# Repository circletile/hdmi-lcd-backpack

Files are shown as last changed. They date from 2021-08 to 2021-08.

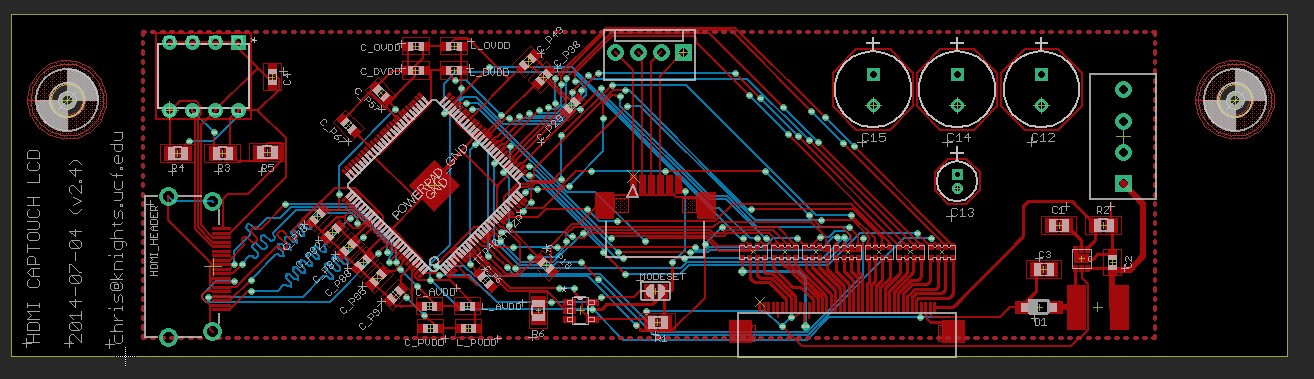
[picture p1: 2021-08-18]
HDMI LCD Backpack PCB.jpg

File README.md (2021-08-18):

# hdmi-lcd-backpack
An HDMI signal converter backpack PCB

A circuit I designed for my electrical/computer engineering senior design project. Takes up to 1080p HDMI video signals, feeds them to a TI TFP401A signal converter, and directly drives an attached LCD. Also provides capacitive touch sensing, backlight control, and DDC data.

A few months later a similar product appeared for sale on Adafruit (#2219). Much easier to just buy theirs than to try to hand solder the TFP401A under a microscope like I did...

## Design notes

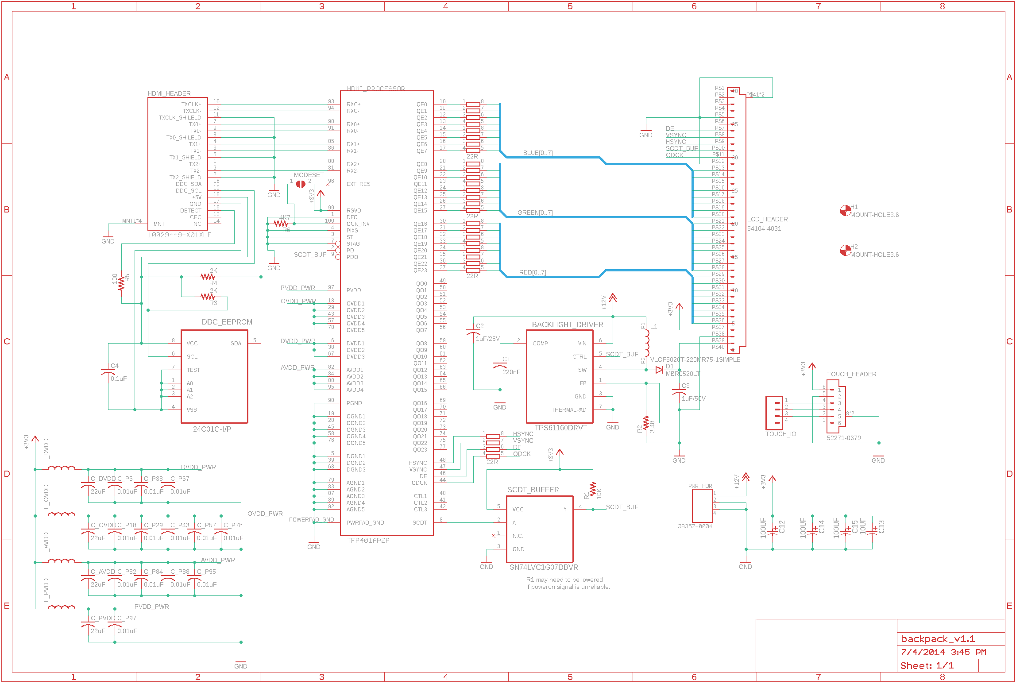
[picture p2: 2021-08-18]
HDMI LCD Backback Schematic.png

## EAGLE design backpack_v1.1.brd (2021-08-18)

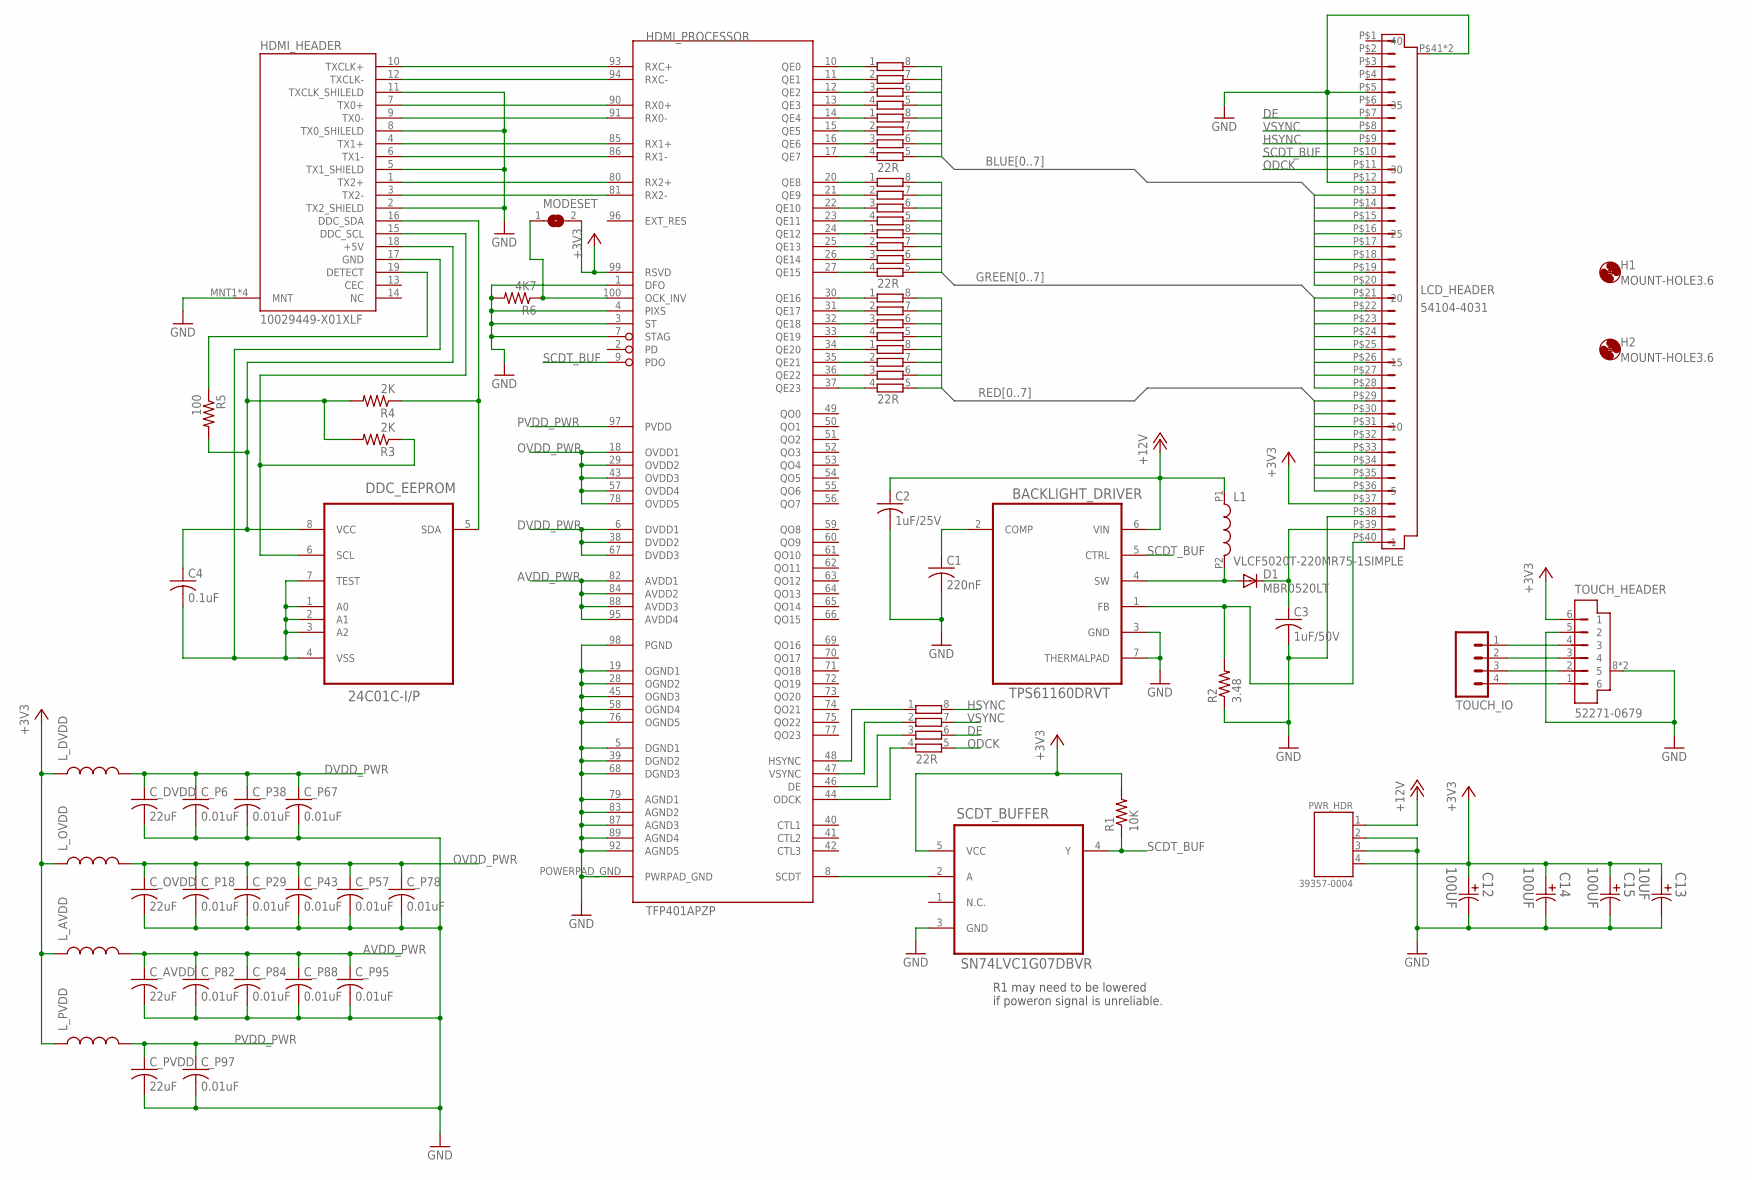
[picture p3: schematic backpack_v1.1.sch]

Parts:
BACKLIGHT_DRIVER: TPS61160DRVT; SON65P210X210X80-7N
C1: 220nF; C0805
C2: 1uF/25V; C0603
C3: 1uF/50V; C0805
C4: 0.1uF; C0603
C12, C14, C15: 100UF; CAPPR350-800X1150
C13: 10UF; CAPPR150-400X700
C_AVDD: 22uF; C0603
C_DVDD: 22uF; C0603
C_OVDD: 22uF; C0603
C_P6, C_P18, C_P29, C_P38, C_P43, C_P57, C_P67, C_P78, C_P82, C_P84, C_P88, C_P95, C_P97: 0.01uF; C0603
C_PVDD: 22uF; C0603
D1: MBR0520LT; SOD123
DDC_EEPROM: 24C01C-I/P; DIP254P762X533-8
H1, H2: MOUNT-HOLE3.6; 3,6
HDMI_HEADER: 10029449-X01XLF; 10029449
HDMI_PROCESSOR: TFP401APZP; 100-TQFP(PZP)
L1: VLCF5020T-220MR75-1SIMPLE; VLCF5020-1_SIMPLE
LCD_HEADER: 54104-4031
L_AVDD: INDUCTOR0603; 0603
L_DVDD: INDUCTOR0603; 0603
L_OVDD: INDUCTOR0603; 0603
L_PVDD: INDUCTOR0603; 0603
MODESET: SJ
PWR_HDR: 39357-0004
R1: 10K; R0805
R2: 3.48; R0805
R3, R4: 2K; R0805
R5: 100; R0805
R6: 4K7; R0805
RN1, RN2, RN3, RN4, RN5, RN6, RN7: 22R; CAY16
SCDT_BUFFER: SN74LVC1G07DBVR; SOT95P280X145-5N
TOUCH_HEADER: 52271-0679
TOUCH_IO: M04POLAR; MOLEX-1X4

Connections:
+3V3: C12.1, C13.1, C14.1, C15.1, HDMI_PROCESSOR.99 (RSVD), LCD_HEADER.P$37 (4), L_AVDD.1, L_DVDD.1, L_OVDD.1, L_PVDD.1, MODESET.2, PWR_HDR.4, R1.2, SCDT_BUFFER.5 (VCC), TOUCH_HEADER.6 (1)
+5V: C4.1, DDC_EEPROM.8 (VCC), HDMI_HEADER.18 (+5V), R3.2, R4.2, R5.2
+12V: BACKLIGHT_DRIVER.6 (VIN), C2.1, L1.P1, PWR_HDR.1
AVDD_PWR: C_AVDD.1, C_P82.1, C_P84.1, C_P88.1, C_P95.1, HDMI_PROCESSOR.82 (AVDD1), HDMI_PROCESSOR.84 (AVDD2), HDMI_PROCESSOR.88 (AVDD3), HDMI_PROCESSOR.95 (AVDD4), L_AVDD.2
BLUE0: LCD_HEADER.P$20 (21), RN1.8 (2)
BLUE1: LCD_HEADER.P$19 (22), RN1.7 (2)
BLUE2: LCD_HEADER.P$18 (23), RN1.6 (2)
BLUE3: LCD_HEADER.P$17 (24), RN1.5 (2)
BLUE4: LCD_HEADER.P$16 (25), RN2.8 (2)
BLUE5: LCD_HEADER.P$15 (26), RN2.7 (2)
BLUE6: LCD_HEADER.P$14 (27), RN2.6 (2)
BLUE7: LCD_HEADER.P$13 (28), RN2.5 (2)
DDC_SCL: DDC_EEPROM.6 (SCL), HDMI_HEADER.15 (DDC_SCL), R3.1
DDC_SDA: DDC_EEPROM.5 (SDA), HDMI_HEADER.16 (DDC_SDA), R4.1
DE: LCD_HEADER.P$7 (34), RN7.6 (2)
DVDD_PWR: C_DVDD.1, C_P6.1, C_P38.1, C_P67.1, HDMI_PROCESSOR.6 (DVDD1), HDMI_PROCESSOR.38 (DVDD2), HDMI_PROCESSOR.67 (DVDD3), L_DVDD.2
GND: BACKLIGHT_DRIVER.3 (GND), BACKLIGHT_DRIVER.7 (THERMALPAD), C1.2, C2.2, C3.2, C12.2, C13.2, C14.2, C15.2, C_AVDD.2, C_DVDD.2, C_OVDD.2, C_P6.2, C_P18.2, C_P29.2, C_P38.2, C_P43.2, C_P57.2, C_P67.2, C_P78.2, C_P82.2, C_P84.2, C_P88.2, C_P95.2, C_P97.2, C_PVDD.2, HDMI_HEADER.2 (TX2_SHIELD), HDMI_HEADER.5 (TX1_SHIELD), HDMI_HEADER.8 (TX0_SHILELD), HDMI_HEADER.11 (TXCLK_SHILELD), HDMI_HEADER.MNT1 (MNT), HDMI_HEADER.MNT2 (MNT), HDMI_HEADER.MNT3 (MNT), HDMI_HEADER.MNT4 (MNT), HDMI_PROCESSOR.1 (DFO), HDMI_PROCESSOR.3 (ST), HDMI_PROCESSOR.4 (PIXS), HDMI_PROCESSOR.5 (DGND1), HDMI_PROCESSOR.7 (STAG), HDMI_PROCESSOR.19 (OGND1), HDMI_PROCESSOR.28 (OGND2), HDMI_PROCESSOR.39 (DGND2), HDMI_PROCESSOR.45 (OGND3), HDMI_PROCESSOR.58 (OGND4), HDMI_PROCESSOR.68 (DGND3), HDMI_PROCESSOR.76 (OGND5), HDMI_PROCESSOR.79 (AGND1), HDMI_PROCESSOR.83 (AGND2), HDMI_PROCESSOR.87 (AGND3), HDMI_PROCESSOR.89 (AGND4), HDMI_PROCESSOR.92 (AGND5), HDMI_PROCESSOR.98 (PGND), HDMI_PROCESSOR.POWERPAD_GND (PWRPAD_GND), LCD_HEADER.P$5 (36), LCD_HEADER.P$12 (29), LCD_HEADER.P$38 (3), LCD_HEADER.P$41 (GND), LCD_HEADER.P$42 (GND), PWR_HDR.2, PWR_HDR.3, R2.1, R6.2, SCDT_BUFFER.3 (GND), TOUCH_HEADER.5 (2), TOUCH_HEADER.8 (GND), TOUCH_HEADER.9 (GND)
GREEN0: LCD_HEADER.P$28 (13), RN3.8 (2)
GREEN1: LCD_HEADER.P$27 (14), RN3.7 (2)
GREEN2: LCD_HEADER.P$26 (15), RN3.6 (2)
GREEN3: LCD_HEADER.P$25 (16), RN3.5 (2)
GREEN4: LCD_HEADER.P$24 (17), RN4.8 (2)
GREEN5: LCD_HEADER.P$23 (18), RN4.7 (2)
GREEN6: LCD_HEADER.P$22 (19), RN4.6 (2)
GREEN7: LCD_HEADER.P$21 (20), RN4.5 (2)
HDMI_DETECT: HDMI_HEADER.19 (DETECT), R5.1
HDMI_GND: C4.2, DDC_EEPROM.1 (A0), DDC_EEPROM.2 (A1), DDC_EEPROM.3 (A2), DDC_EEPROM.4 (VSS), DDC_EEPROM.7 (TEST), HDMI_HEADER.17 (GND)
HSYNC: LCD_HEADER.P$9 (32), RN7.8 (2)
unnamed: HDMI_PROCESSOR.10 (QE0), RN1.1
unnamed: HDMI_PROCESSOR.11 (QE1), RN1.2 (1)
unnamed: HDMI_PROCESSOR.12 (QE2), RN1.3 (1)
unnamed: HDMI_PROCESSOR.13 (QE3), RN1.4 (1)
unnamed: HDMI_PROCESSOR.14 (QE4), RN2.1
unnamed: HDMI_PROCESSOR.15 (QE5), RN2.2 (1)
unnamed: HDMI_PROCESSOR.16 (QE6), RN2.3 (1)
unnamed: HDMI_PROCESSOR.17 (QE7), RN2.4 (1)
unnamed: HDMI_PROCESSOR.20 (QE8), RN3.1
unnamed: HDMI_PROCESSOR.21 (QE9), RN3.2 (1)
unnamed: HDMI_PROCESSOR.22 (QE10), RN3.3 (1)
unnamed: HDMI_PROCESSOR.23 (QE11), RN3.4 (1)
unnamed: HDMI_PROCESSOR.24 (QE12), RN4.1
unnamed: HDMI_PROCESSOR.25 (QE13), RN4.2 (1)
unnamed: HDMI_PROCESSOR.26 (QE14), RN4.3 (1)
unnamed: HDMI_PROCESSOR.27 (QE15), RN4.4 (1)
unnamed: HDMI_PROCESSOR.30 (QE16), RN5.1
unnamed: HDMI_PROCESSOR.31 (QE17), RN5.2 (1)
unnamed: HDMI_PROCESSOR.32 (QE18), RN5.3 (1)
unnamed: HDMI_PROCESSOR.33 (QE19), RN5.4 (1)
unnamed: HDMI_PROCESSOR.34 (QE20), RN6.1
unnamed: HDMI_PROCESSOR.35 (QE21), RN6.2 (1)
unnamed: HDMI_PROCESSOR.36 (QE22), RN6.3 (1)
unnamed: HDMI_PROCESSOR.37 (QE23), RN6.4 (1)
unnamed: BACKLIGHT_DRIVER.4 (SW), D1.A, L1.P2
unnamed: BACKLIGHT_DRIVER.2 (COMP), C1.1
unnamed: BACKLIGHT_DRIVER.1 (FB), LCD_HEADER.P$40 (1), R2.2
unnamed: HDMI_PROCESSOR.44 (ODCK), RN7.4 (1)
unnamed: C3.1, D1.C, LCD_HEADER.P$39 (2)
unnamed: HDMI_PROCESSOR.46 (DE), RN7.3 (1)
unnamed: HDMI_PROCESSOR.47 (VSYNC), RN7.2 (1)
unnamed: HDMI_PROCESSOR.48 (HSYNC), RN7.1
unnamed: TOUCH_HEADER.4 (3), TOUCH_IO.1
unnamed: TOUCH_HEADER.3 (4), TOUCH_IO.2
unnamed: TOUCH_HEADER.2 (5), TOUCH_IO.3
unnamed: TOUCH_HEADER.1 (6), TOUCH_IO.4
OCK_INV: HDMI_PROCESSOR.100 (OCK_INV), MODESET.1, R6.1
ODCK: LCD_HEADER.P$11 (30), RN7.5 (2)
OVDD_PWR: C_OVDD.1, C_P18.1, C_P29.1, C_P43.1, C_P57.1, C_P78.1, HDMI_PROCESSOR.18 (OVDD1), HDMI_PROCESSOR.29 (OVDD2), HDMI_PROCESSOR.43 (OVDD3), HDMI_PROCESSOR.57 (OVDD4), HDMI_PROCESSOR.78 (OVDD5), L_OVDD.2
PVDD_PWR: C_P97.1, C_PVDD.1, HDMI_PROCESSOR.97 (PVDD), L_PVDD.2
RED0: LCD_HEADER.P$36 (5), RN5.8 (2)
RED1: LCD_HEADER.P$35 (6), RN5.7 (2)
RED2: LCD_HEADER.P$34 (7), RN5.6 (2)
RED3: LCD_HEADER.P$33 (8), RN5.5 (2)
RED4: LCD_HEADER.P$32 (9), RN6.8 (2)
RED5: LCD_HEADER.P$31 (10), RN6.7 (2)
RED6: LCD_HEADER.P$30 (11), RN6.6 (2)
RED7: LCD_HEADER.P$29 (12), RN6.5 (2)
SCDT: HDMI_PROCESSOR.8 (SCDT), SCDT_BUFFER.2 (A)
SCDT_BUF: BACKLIGHT_DRIVER.5 (CTRL), HDMI_PROCESSOR.9 (PDO), LCD_HEADER.P$10 (31), R1.1, SCDT_BUFFER.4 (Y)
TX0_N: HDMI_HEADER.9 (TX0-), HDMI_PROCESSOR.91 (RX0-)
TX0_P: HDMI_HEADER.7 (TX0+), HDMI_PROCESSOR.90 (RX0+)
TX1_N: HDMI_HEADER.6 (TX1-), HDMI_PROCESSOR.86 (RX1-)
TX1_P: HDMI_HEADER.4 (TX1+), HDMI_PROCESSOR.85 (RX1+)
TX2_N: HDMI_HEADER.3 (TX2-), HDMI_PROCESSOR.81 (RX2-)
TX2_P: HDMI_HEADER.1 (TX2+), HDMI_PROCESSOR.80 (RX2+)
TXCLK_N: HDMI_HEADER.12 (TXCLK-), HDMI_PROCESSOR.94 (RXC-)
TXCLK_P: HDMI_HEADER.10 (TXCLK+), HDMI_PROCESSOR.93 (RXC+)
VSYNC: LCD_HEADER.P$8 (33), RN7.7 (2)

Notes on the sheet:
R1 may need to be lowered if poweron signal is unreliable.

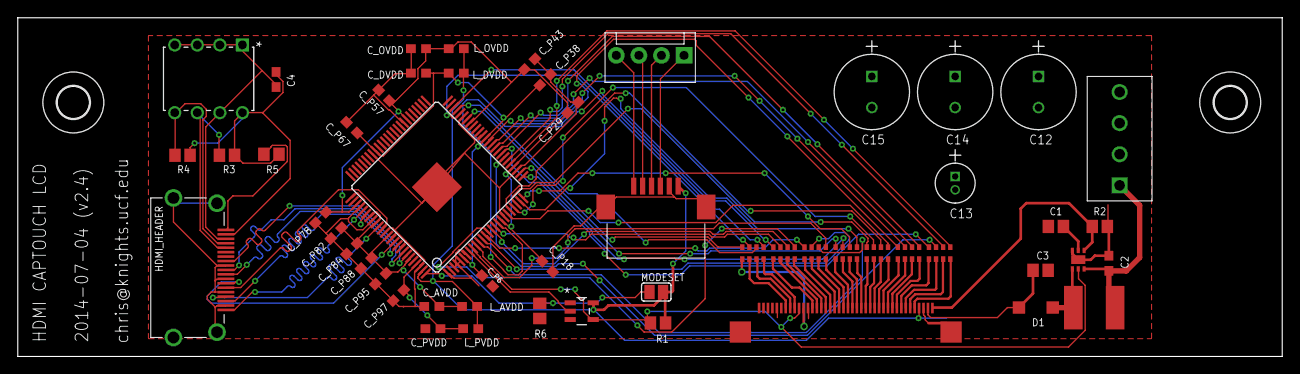
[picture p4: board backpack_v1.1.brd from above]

Board: 2 copper layers, 142.2 x 38.1 mm, 56 parts (0 on the bottom side), 87 nets.

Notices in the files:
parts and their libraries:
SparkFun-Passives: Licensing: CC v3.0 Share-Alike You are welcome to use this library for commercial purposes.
